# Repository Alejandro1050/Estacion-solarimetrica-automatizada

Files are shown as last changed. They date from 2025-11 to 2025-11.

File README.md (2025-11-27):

# 🌞 Sistema Automatizado de Adquisición de Datos Solarimétricos

Prototipo de un sistema automatizado para la adquisición, procesamiento y visualización de datos solarimétricos en Cancún, Quintana Roo.

**Proyecto Terminal** - Ingeniería en Datos e Inteligencia Organizacional | Ingeniería Ambiental con especialidad en Energías Renovables

---

## 📋 Tabla de Contenidos

- [Descripción del Proyecto](#descripción-del-proyecto)
- [Características](#características)
- [Estructura del Proyecto](#estructura-del-proyecto)
- [Instalación](#instalación)
- [Configuración](#configuración)
- [Uso](#uso)
- [Especificaciones Técnicas](#especificaciones-técnicas)
- [Autores](#autores)
- [Licencia](#licencia)

---

## 📖 Descripción del Proyecto

Este repositorio contiene toda la documentación, código y especificaciones de hardware necesarias para un sistema completo de monitoreo solar. El sistema realiza la adquisición automática de datos solarimétricos, procesamiento en tiempo real (ETL), y visualización mediante un dashboard interactivo en Dash.

### Objetivos

- ✅ Automatizar la adquisición de datos solarimétricos
- ✅ Procesar y almacenar datos de forma eficiente
- ✅ Visualizar datos en tiempo real mediante dashboard web
- ✅ Generar alertas automáticas por anomalías
- ✅ Mantener historial completo de mediciones

---

## ⭐ Características

- **Backend robusto**: Servidor Python con ETL automático, MQTT y API REST
- **Frontend interactivo**: Dashboard en tiempo real con Dash
- **Microcontroladores**: Firmware especializado para ESP32 y Arduino
- **Múltiples sensores**: Piranómetros, termopares y sensores ambientales
- **Logging centralizado**: Sistema de logs con rotación automática
- **Alertas por email**: Notificación de anomalías en tiempo real
- **Simulación**: Modo simulador para pruebas sin hardware

---

## 📁 Estructura del Proyecto

```
Estacion-solarimetrica-automatizada/
├── Backend/                          # Servidor Python
│   ├── main.py                      # Gestor principal de procesos
│   ├── endpoint.py                  # API REST
│   ├── etl.py                       # Procesamiento de datos
│   ├── load.py                      # Carga a base de datos
│   ├── email_alert.py               # Sistema de alertas por email
│   ├── graficas_insolacion.py       # Generación de gráficos
│   ├── logging_config.py            # Configuración de logs
│   └── simulador.py                 # Simulador de datos
├── Frontend/                         # Interfaz web
│   └── app.py                       # Dashboard Dash
├── Modulos/                          # Hardware y Firmware
│   ├── Ambiental/                   # Módulo de temperatura/humedad
│   │   ├── Firmware/
│   │   │   ├── Arduino_dht/
│   │   │   └── ESP32_sht/
│   │   └── PCB/
│   ├── Datalogger/                  # Módulo datalogger
│   │   ├── Firmware/
│   │   │   ├── Datalogger/
│   │   │   ├── Datalogger_V2/
│   │   │   ├── Datalogger_V3/
│   │   │   └── Datalogger_V4/
│   │   └── PCB/
│   └── Termopares/                  # Módulo termopares
│       ├── Firmware/
│       │   └── Arduino_termo/
|       |   |__ ESP32_termo/
│       └── PCB/
├── LICENSE
└── README.md
```

---

## 💻 Instalación

### Requisitos Previos

- **Python 3.13** o superior
- **Mosquitto Broker** para comunicación MQTT
- **pip** (gestor de paquetes de Python)

### Paso 1: Clonar el Repositorio

```bash
git clone https://github.com/Alejandro1050/Estacion-solarimetrica-automatizada.git
cd Estacion-solarimetrica-automatizada
```

### Paso 2: Instalar Mosquitto Broker

```bash
# En sistemas Debian/Ubuntu
sudo apt update
sudo apt install mosquitto mosquitto-clients

# Iniciar el servicio
sudo systemctl start mosquitto
sudo systemctl enable mosquitto
```

### Paso 3: Instalar Dependencias Python

```bash
# Crear entorno virtual (recomendado)
python3 -m venv venv
source venv/bin/activate

# Instalar paquetes
pip3 install -r requirements.txt
```

### Paso 4: Cargar Firmware en Microcontroladores

1. **Datalogger**: Usar Arduino IDE para cargar `Modulos/Datalogger/Firmware/Datalogger_V4/Datalogger_V4.ino`
2. **Módulo Ambiental**: Cargar `Modulos/Ambiental/Firmware/ESP32-Ambi/ESP32-Ambi.ino`
3. **Termopares**: Cargar `Modulos/Termopares/Firmware/Termocuplas/Termocuplas.ino`

---

## ⚙️ Configuración

### Ubicación Geográfica

Ubicación instalada en Cancún, Quintana Roo:

| Parámetro | Valor |
|---|---|
| **Latitud** | 21°54'07" N |
| **Longitud** | 86°49'48" O |
| **Altura** | 6 m sobre el nivel del mar |
| **Zona horaria** | America/Cancun (UTC-6, UTC-5 con DST) |

### Configuración de Piranómetros

El sistema cuenta con dos piranómetros de precisión estándar (SPP):

| Sensor | Modelo | Constante Calibración | Canal Datalogger | Medición |
|---|---|---|---|---|
| **Piranómetro 1** | SPP | 8.66 µV/(W/m²) | Canal 1 | DHI (Irradiancia Horizontal Difusa) |
| **Piranómetro 2** | SPP | 8.72 µV/(W/m²) | Canal 2 | GHI (Irradiancia Horizontal Global) |

### Variables Medidas

El sistema recopila las siguientes variables:

- **DHI**: Irradiancia Horizontal Difusa (W/m²)
- **GHI**: Irradiancia Horizontal Global (W/m²)
- **DNI**: Irradiancia Normal Directa (W/m²) - calculada
- **Temperatura 1**: Termocupla 1 (°C)
- **Temperatura 2**: Termocupla 2 (°C)
- **Temperatura Ambiente**: Sensor SHT31 (°C)
- **Humedad Ambiente**: Sensor SHT31 (%)
- **Ángulo Cenital Solar**: Calculado en tiempo real (°)

---

## 🚀 Uso

### Iniciar el Sistema Completo

```bash
# Con entorno virtual activado
cd Backend
python3 main.py
```

Esto inicia automáticamente:
- ETL (procesamiento de datos)
- Endpoint API (disponible en `http://localhost:5001`)
- Frontend (dashboard disponible en `http://localhost:8050`)

### Ejecutar Componentes de Forma Independiente

**Solo Backend (API + ETL)**:
```bash
cd Backend
python3 main.py
```

**Solo Frontend (Dashboard)**:
```bash
cd Frontend
python3 app.py
```

**Modo Simulador** (para pruebas sin hardware):
```bash
cd Backend
python3 simulador.py
```

### Acceder al Dashboard

Una vez iniciado el sistema, abre tu navegador en:

```
http://localhost:8050
```

El dashboard te permite:
- Ver gráficos en tiempo real
- Consultar historial de datos
- Monitorear alertas
- Descargar datos

---

## 🔧 Especificaciones Técnicas

### Stack Tecnológico

**Backend:**
- Python 3.13
- Flask/API REST
- MQTT (Mosquitto)
- Polars para procesamiento de datos

**Frontend:**
- Dash (Plotly)
- Bootstrap para UI
- WebSocket para tiempo real

**Hardware:**
- ESP32-C3 para adquisición
- Piranómetros SPP
- Termopares tipo K
- Sensor SHT31

### Comunicación

- **MQTT**: Comunicación en tiempo real con sensores (puerto 1883)
- **REST API**: Acceso a datos históricos (puerto 5001)
- **HTTP**: Dashboard web (puerto 8050)

## 📊 Funcionalidades Principales

### ETL (Extract, Transform, Load)
- Extrae datos de MQTT en tiempo real
- Transforma y valida mediciones
- Calcula variables derivadas (DNI, ángulo zenital)
- Carga en base de datos

### Alertas
- Detección de anomalías automática
- Notificaciones por email
- Histórico de alertas

### Visualización
- Gráficos interactivos en tiempo real
- Análisis histórico
- Exportación de datos

---

## 🐛 Troubleshooting

**El dashboard no se conecta:**
- Verificar que Mosquitto está corriendo: `systemctl status mosquitto`
- Verificar logs: `tail -f data/logs/solarserver.log`

**Error de conexión MQTT:**
- Reiniciar Mosquitto: `sudo systemctl restart mosquitto`
- Verificar firewall: `sudo ufw allow 1883`

**API no responde:**
- Verificar que endpoint.py está ejecutándose
- Revisar puerto 5001: `lsof -i :5001`

---

## 📝 Licencia

Este proyecto está licenciado bajo [ver LICENSE](./LICENSE)

---

## 👥 Autores

Mel josé Cahuich Garcia - ing. ambiental 

Correo: 200300847@ucaribe.edu.mx

Carlos Alejandro Cordova Cocom - Ing. en datos e inteligencia organizacional

correo: 200300617@ucaribe.edu.mx

Nayeli Pérez Tun - Ing. ambiental 

correo: 200300850@ucaribe.edu.mx

Paola Ariana Tut Cupul - Ing. ambiental 

correo: 200300832@ucaribe.edu.mx

---

## 📞 Soporte

Para reportar problemas o sugerencias, crea un [issue](https://github.com/Alejandro1050/Estacion-solarimetrica-automatizada/issues) en el repositorio.

---

**Última actualización**: 27 de noviembre de 2025

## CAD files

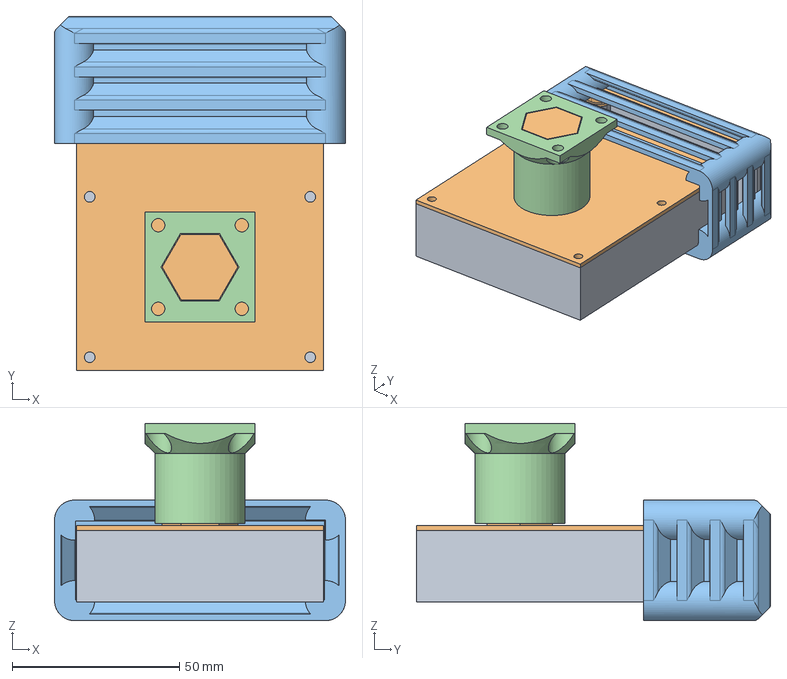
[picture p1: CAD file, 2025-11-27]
Modulos/Ambiental/Step files/Módulo ambiental V2.step
87.1 x 106.0 x 59.0 mm

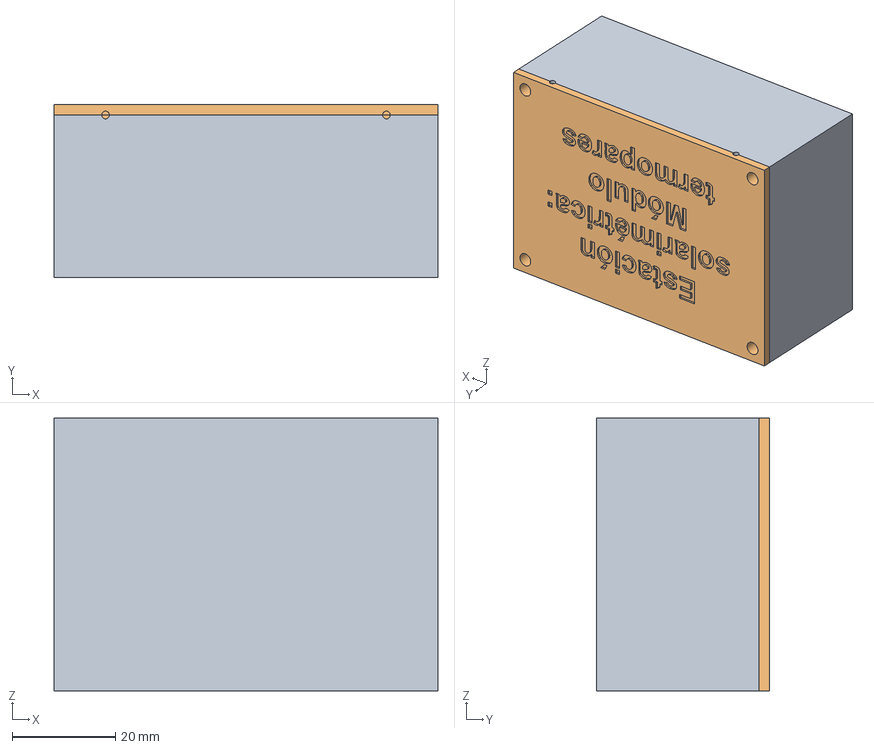
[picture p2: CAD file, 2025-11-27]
Modulos/Termopares/Step files/Módulo termocúplas.step
74.5 x 33.5 x 52.9 mm

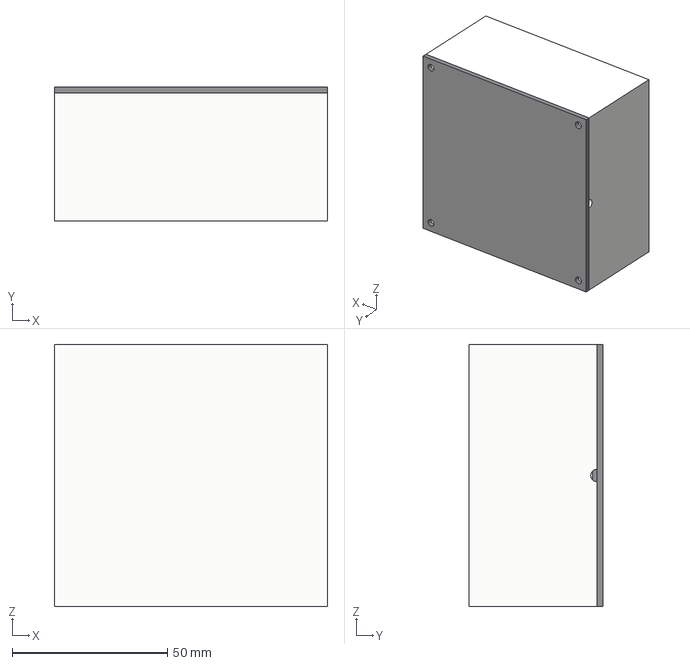
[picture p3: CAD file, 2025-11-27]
Modulos/Termopares/Step files/Termopares V1.step
87.8 x 43.2 x 84.4 mm

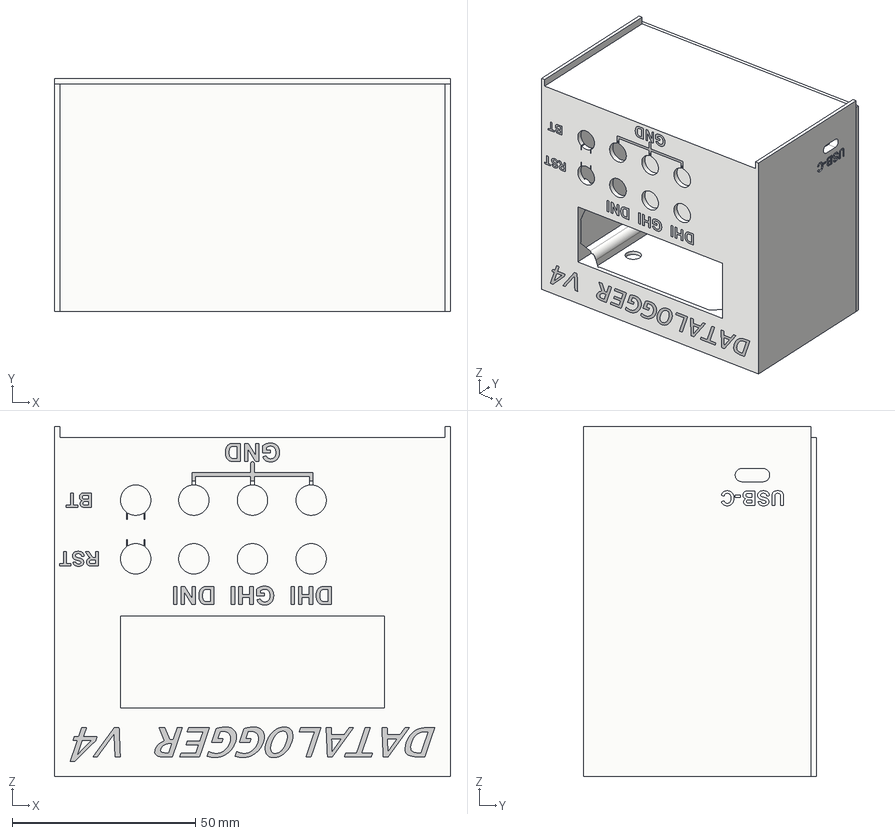
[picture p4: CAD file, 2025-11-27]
Modulos/Datalogger/Step files/Datalogger V3.step
108.0 x 63.6 x 95.6 mm

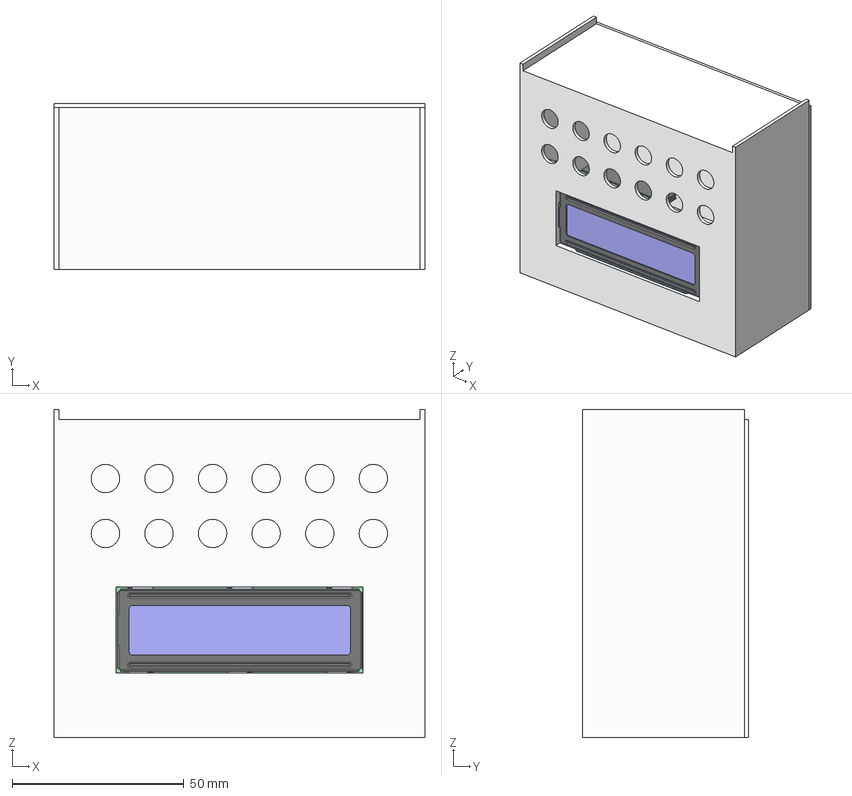
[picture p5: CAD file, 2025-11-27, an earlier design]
Modulos/Datalogger/Step files/Datalogger V2.step
108.0 x 48.3 x 95.6 mm
LCD_PCB
metal_casing
LCDbacklight
LCD_1
conductors x 2
1x8 Male Pin Header x 2
Header Female 1x16.step

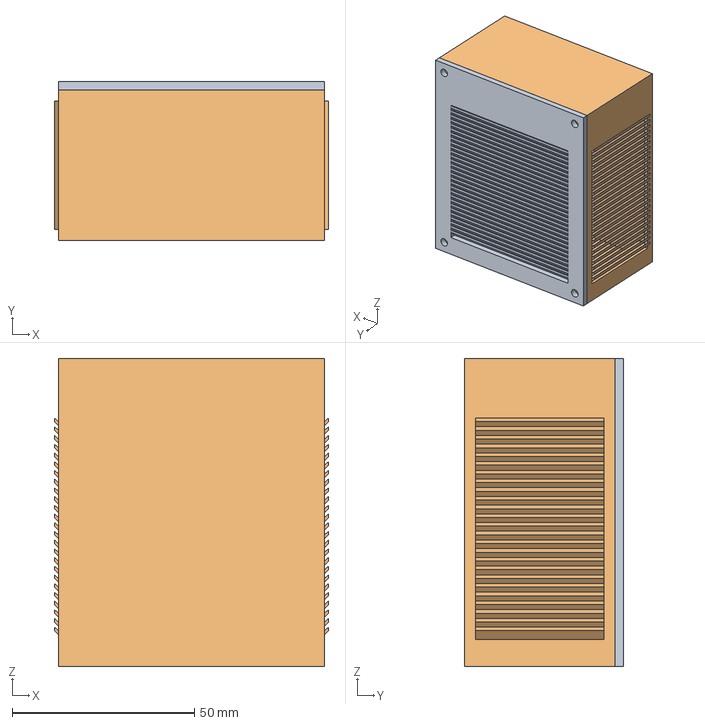
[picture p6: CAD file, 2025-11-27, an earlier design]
Modulos/Ambiental/Step files/Módulo ambiental v1.step
75.1 x 43.6 x 84.4 mm

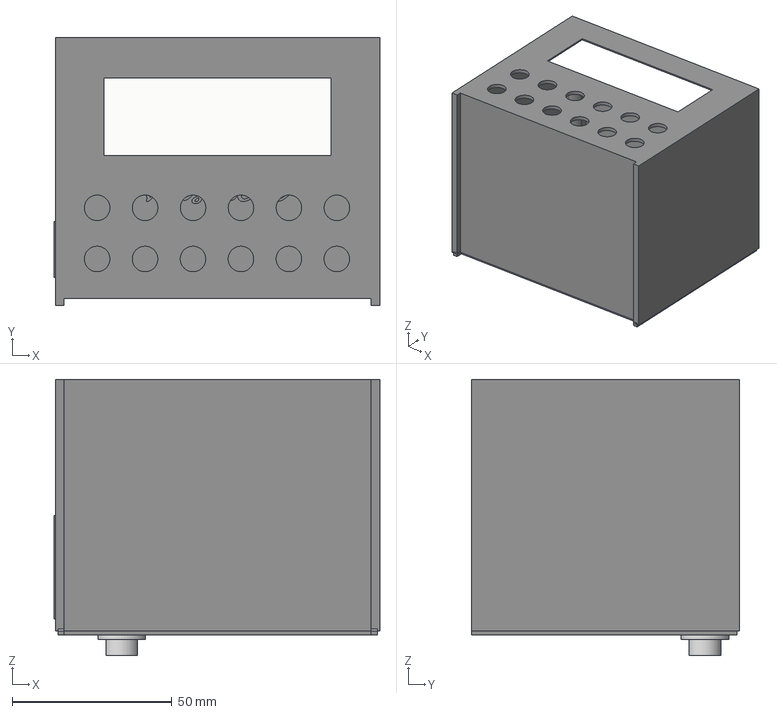
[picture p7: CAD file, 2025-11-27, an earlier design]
Modulos/Datalogger/Step files/Datalogger V1.step
102.0 x 83.8 x 86.5 mm

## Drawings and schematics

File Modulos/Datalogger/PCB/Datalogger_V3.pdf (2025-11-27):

Placa Principal | Placa I2C

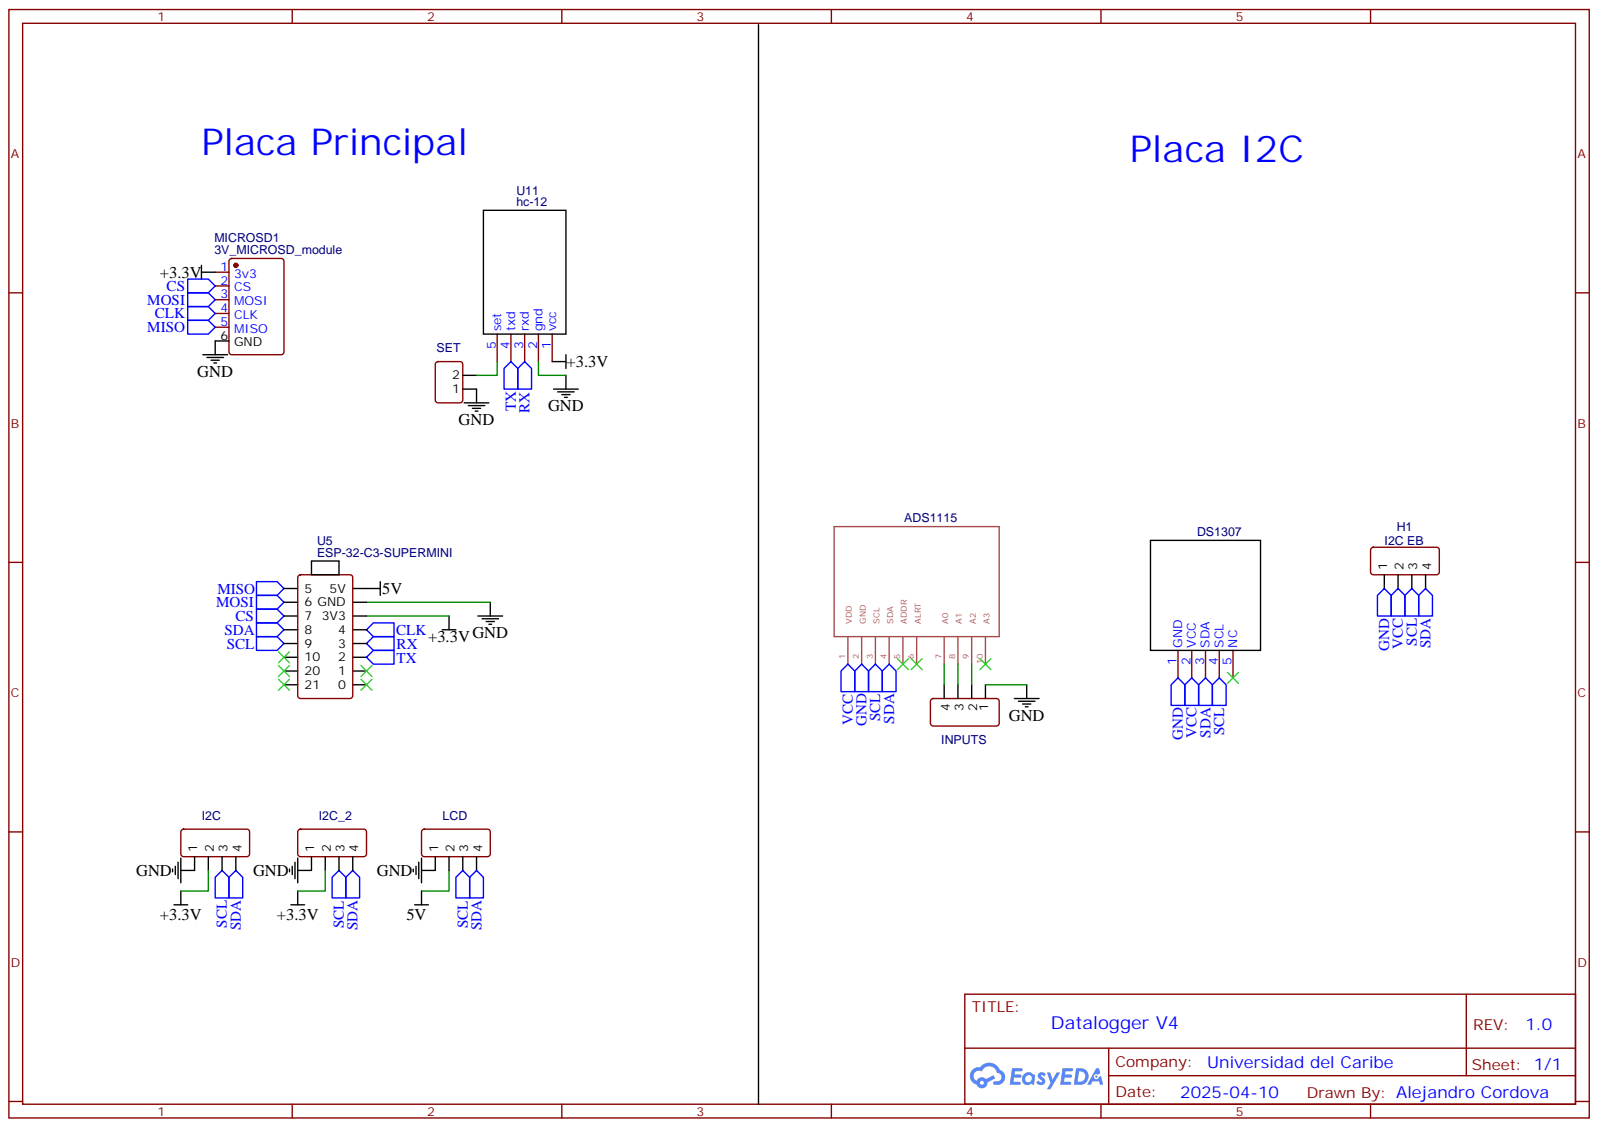
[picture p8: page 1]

Company: Universidad del Caribe

Drawn By: Alejandro Cordova

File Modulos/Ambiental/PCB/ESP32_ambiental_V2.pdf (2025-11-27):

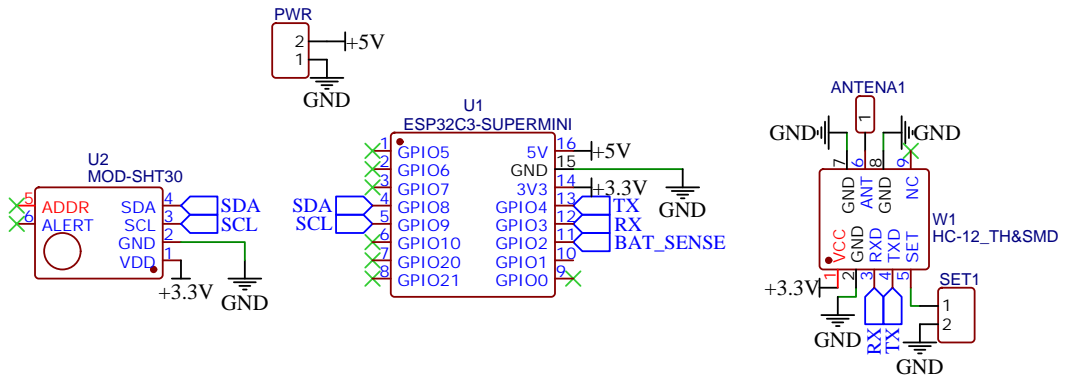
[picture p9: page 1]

Company: Universidad del Caribe

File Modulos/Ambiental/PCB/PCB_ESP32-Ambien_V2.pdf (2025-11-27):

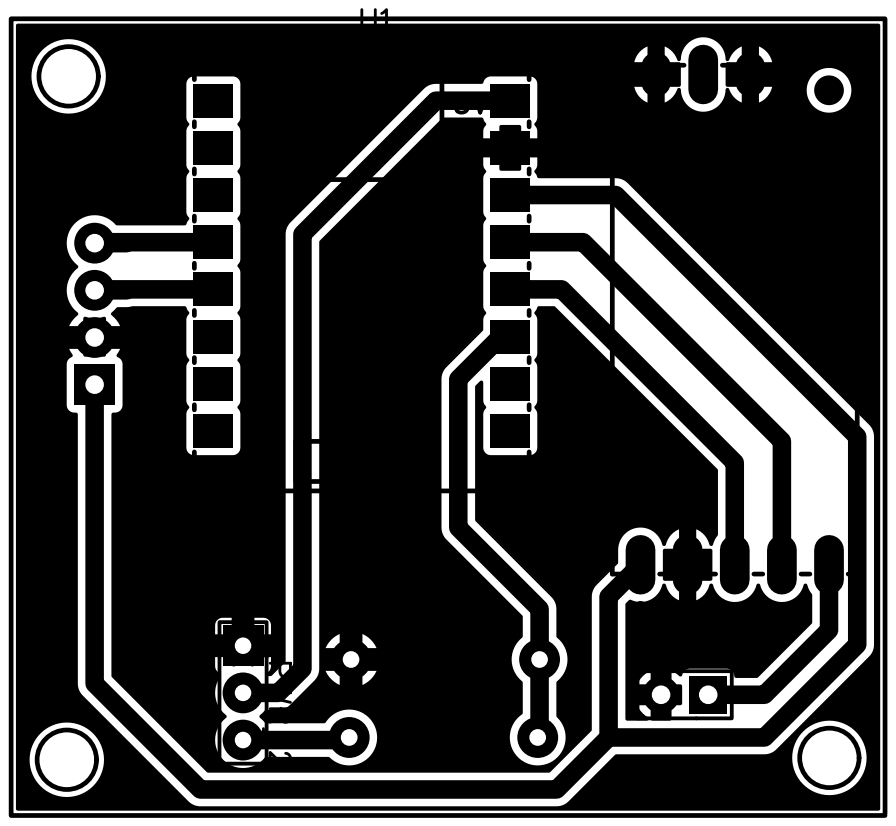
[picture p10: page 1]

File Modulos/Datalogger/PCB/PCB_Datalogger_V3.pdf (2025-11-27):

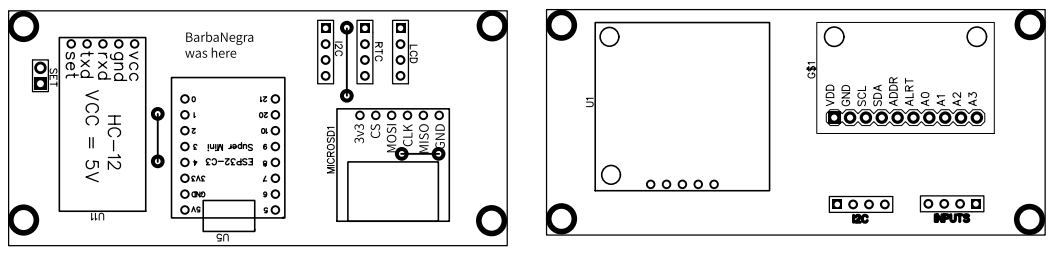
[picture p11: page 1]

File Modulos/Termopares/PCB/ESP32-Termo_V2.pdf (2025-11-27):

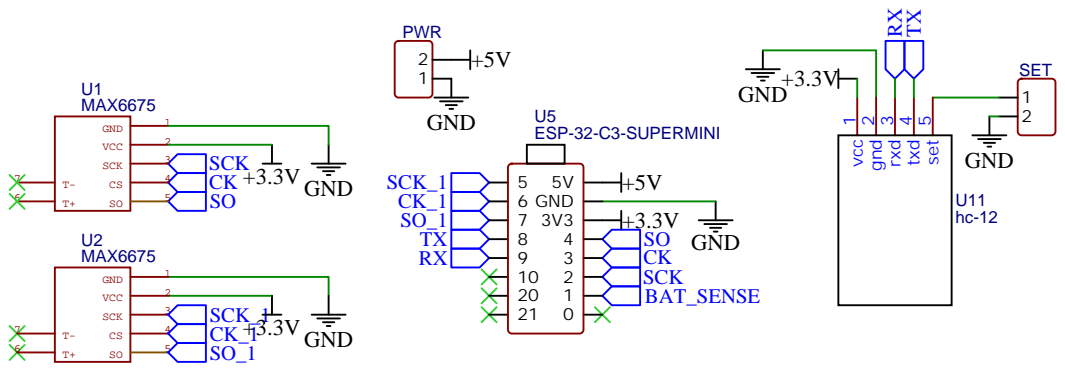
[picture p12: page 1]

Company: Universidad del Caribe

Drawn By: Alejandro Cordova

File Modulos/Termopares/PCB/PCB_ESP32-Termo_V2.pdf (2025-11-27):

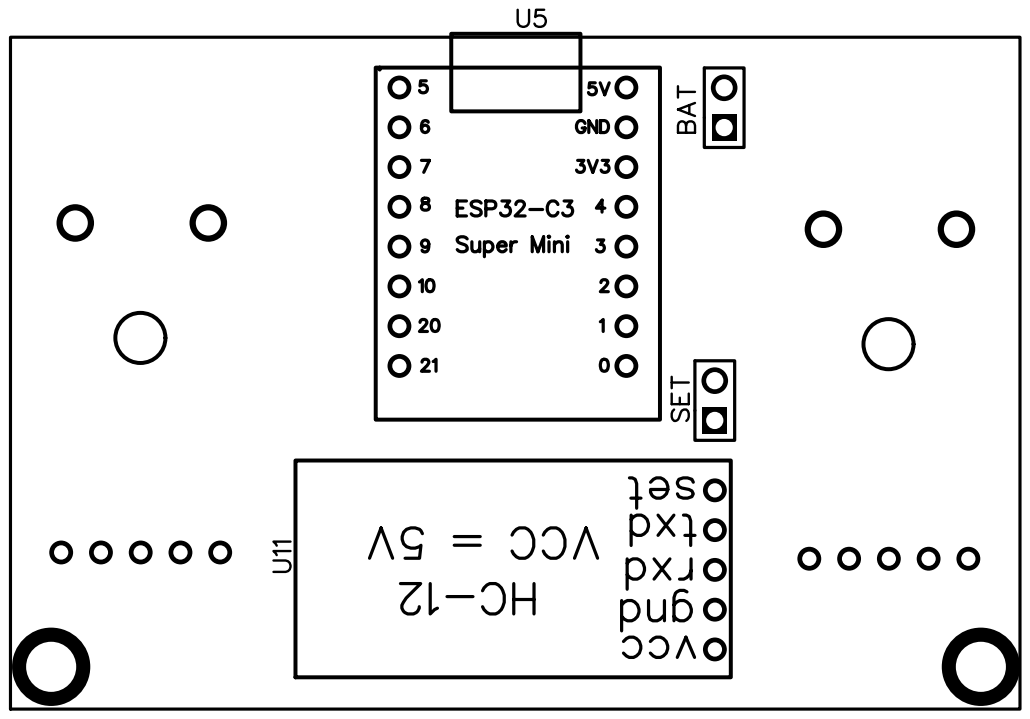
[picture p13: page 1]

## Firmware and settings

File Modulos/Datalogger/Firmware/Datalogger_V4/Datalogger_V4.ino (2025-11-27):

#include "FS.h"
#include "SD.h"
#include "SPI.h"
#include <Wire.h>
#include <Adafruit_ADS1X15.h>
#include <WiFi.h>
#include <PubSubClient.h>
#include "RTClib.h"
#include <LiquidCrystal_I2C.h>

RTC_DS1307 rtc;

LiquidCrystal_I2C lcd(0x27, 16, 2);

// Configuración WiFi
const char* ssid = "LER";
const char* password = "datos_manda";

// Configuración MQTT
const char* mqtt_server = "192.168.1.3";
const int mqtt_port = 1883;
const char* mqtt_topic = "esp32/sensors";
const char* mqtt_command_topic = "esp32/commands";

// Definición de pines
#define HC12_RX_PIN 3  // Conectar TX del HC-12
#define HC12_TX_PIN 2  // Conectar RX del HC-12
#define SD_CS_PIN 7    // Pin Chip Select para la SD

HardwareSerial hc(1);  // UART1 para HC-12
Adafruit_ADS1115 ads;

// Variables para el manejo del tiempo
const long interval = 60000;
unsigned long previousMillis = 0;

// Variables de estado
bool SD_Error = false;
bool wifiConnected = false;
bool mqttConnected = false;
int connectionAttempts = 0;
File dataFile;

// Inicializar el cliente WiFi y MQTT
WiFiClient espClient;
PubSubClient client(espClient);

// Función para conectarse al Wifi
void setup_wifi() {
  delay(10);
  Serial.println();
  Serial.print("Conectando a: ");
  Serial.println(ssid);

  lcd.clear();
  lcd.setCursor(0, 0);
  lcd.print("Conectando WiFi");
  lcd.setCursor(0, 1);
  lcd.print(ssid);

  // Configuración específica para ESP32-C3
  WiFi.mode(WIFI_STA);
  WiFi.setAutoReconnect(true);
  WiFi.setTxPower(WIFI_POWER_19_5dBm);  // Aumentar potencia de transmisión
  WiFi.setHostname("Datalogger-C3");

  // Limpiar configuración previa
  WiFi.disconnect(true);
  delay(2000);

  // Configurar parámetros WiFi específicos
  WiFi.setScanMethod(WIFI_ALL_CHANNEL_SCAN);
  WiFi.setSortMethod(WIFI_CONNECT_AP_BY_SIGNAL);

  Serial.println("Iniciando conexión...");
  WiFi.begin(ssid, password);

  int attempts = 0;
  while (WiFi.status() != WL_CONNECTED && attempts < 25) {
    delay(1000);
    Serial.print("Intento ");
    Serial.print(attempts);
    Serial.print(" - Estado: ");
    Serial.println(WiFi.status());

    // Mostrar punto en LCD
    lcd.setCursor(attempts, 1);
    lcd.print(".");

    attempts++;

    // Reiniciar conexión después de 10 intentos
    if (attempts == 10) {
      Serial.println("Reiniciando conexión WiFi...");
      WiFi.disconnect();
      delay(1000);
      WiFi.begin(ssid, password);
    }
  }

  if (WiFi.status() == WL_CONNECTED) {
    wifiConnected = true;
    Serial.println("WiFi CONECTADO!");
    Serial.print("IP: ");
    Serial.println(WiFi.localIP());
    Serial.print("RSSI: ");
    Serial.println(WiFi.RSSI());

    lcd.clear();
    lcd.setCursor(0, 0);
    lcd.print("WiFi Conectado");
    lcd.setCursor(0, 1);
    lcd.print("IP: ");
    lcd.print(WiFi.localIP());
  } else {
    wifiConnected = false;
    Serial.println("FALLA en conexión WiFi");
    Serial.print("Último estado: ");
    Serial.println(WiFi.status());

    lcd.clear();
    lcd.setCursor(0, 0);
    lcd.print("Error WiFi");
    lcd.setCursor(0, 1);
    lcd.print("Estado ");
    lcd.print(WiFi.status());
  }
  delay(2000);
}

void wifiDiagnostic() {
  Serial.println("\n=== DIAGNÓSTICO WiFi DETALLADO ===");

  // Verificar si el SSID está disponible
  Serial.println("Escaneando redes...");
  int n = WiFi.scanNetworks();
  Serial.print("Redes encontradas: ");
  Serial.println(n);

  bool networkFound = false;
  for (int i = 0; i < n; ++i) {
    Serial.print(i + 1);
    Serial.print(": ");
    Serial.print(WiFi.SSID(i));
    Serial.print(" (");
    Serial.print(WiFi.RSSI(i));
    Serial.print(" dBm) ");
    Serial.println((WiFi.encryptionType(i) == WIFI_AUTH_OPEN) ? "Abierta" : "Protegida");

    if (WiFi.SSID(i) == ssid) {
      networkFound = true;
      Serial.print("*** RED LER ENCONTRADA - Señal: ");
      Serial.print(WiFi.RSSI(i));
      Serial.println(" dBm ***");
    }
  }

  if (!networkFound) {
    Serial.println("*** ADVERTENCIA: Red LER no encontrada ***");
  }

  Serial.print("Estado WiFi: ");
  switch (WiFi.status()) {
    case WL_IDLE_STATUS: Serial.println("WL_IDLE_STATUS (0)"); break;
    case WL_NO_SSID_AVAIL: Serial.println("WL_NO_SSID_AVAIL (1) - SSID no disponible"); break;
    case WL_SCAN_COMPLETED: Serial.println("WL_SCAN_COMPLETED (2)"); break;
    case WL_CONNECTED: Serial.println("WL_CONNECTED (3)"); break;
    case WL_CONNECT_FAILED: Serial.println("WL_CONNECT_FAILED (4) - Falló conexión"); break;
    case WL_CONNECTION_LOST: Serial.println("WL_CONNECTION_LOST (5) - Conexión perdida"); break;
    case WL_DISCONNECTED: Serial.println("WL_DISCONNECTED (6) - Desconectado"); break;
    default: Serial.println("Desconocido"); break;
  }

  Serial.print("MAC: ");
  Serial.println(WiFi.macAddress());
  Serial.println("=== FIN DIAGNÓSTICO ===\n");
}
void reconnectMQTT() {
  while (!client.connected() && connectionAttempts < 10) {
    Serial.print("Intentando conexión MQTT...");
    lcd.clear();
    lcd.setCursor(0, 0);
    lcd.print("Servidor:");
    lcd.setCursor(0, 1);
    lcd.print("Conectando...");
    delay(500);

    // Crear un ID de cliente aleatorio
    String clientId = "DATALOGGER-";
    clientId += String(random(0xffff), HEX);

    // Intentar conectar
    if (client.connect(clientId.c_str())) {
      Serial.println("conectado");
      lcd.clear();
      lcd.setCursor(0, 0);
      lcd.print("Servidor:");
      lcd.setCursor(0, 1);
      lcd.print("Conectado");
      delay(500);

      // Suscribirse al tema de comandos
      client.subscribe(mqtt_command_topic);

    } else {
      Serial.print("falló, rc=");
      Serial.print(client.state());
      connectionAttempts++;
      if (connectionAttempts == 10) {
        mqttConnected = false;
        Serial.println("MQTT Error!");
        lcd.clear();
        lcd.setCursor(0, 0);
        lcd.print("Servidor:");
        lcd.setCursor(0, 1);
        lcd.print("Error!");
        delay(500);
      } else {
        Serial.println(" intentando de nuevo en 5 segundos");
      }
      delay(5000);
    }
  }
}

String getVoltage() {
  int16_t adc0 = ads.readADC_SingleEnded(0);
  int16_t adc1 = ads.readADC_SingleEnded(1);

  float ch1 = ads.computeVolts(adc0) * 1000.0f;
  float ch2 = ads.computeVolts(adc1) * 1000.0f;

  if (ch1 < 0.0 || ch1 > 11.0) {
    ch1 = 0.0;
  }
  if (ch2 < 0.0 || ch2 > 11.0) {
    ch2 = 0.0;
  }

  lcd.clear();
  lcd.setCursor(0, 0);
  lcd.print("Difusa (mv): ");
  lcd.setCursor(12, 0);
  lcd.print(ch1, 2);
  lcd.setCursor(0, 1);
  lcd.print("Global (mV): ");
  lcd.setCursor(12, 1);
  lcd.print(ch2, 2);

  return String(ch1, 2) + "," + String(ch2, 2);
}

String get_data(int id) {
  while (hc.available()) hc.read();  // Limpiar buffer
er
  hc.println(id);  // Enviar solicitud

  unsigned long startTime = millis();
  while (millis() - startTime < 1000) {
    if (hc.available()) {
      String data = hc.readStringUntil('\n');
      data.trim();
      if (data.length() > 0) {
        return data;
      }
    }
  }
  return "Nan,Nan,Nan";
}

bool init_SD() {
  if (!SD.begin(SD_CS_PIN)) {
    Serial.println("Error al inicializar la tarjeta SD");
    return false;
  }

  uint8_t cardType = SD.cardType();
  if (cardType == CARD_NONE) {
    Serial.println("No se detectó tarjeta SD");
    return false;
  }

  // Crear archivo con encabezados si no existe
  if (!SD.exists("/data.csv")) {
    File file = SD.open("/data.csv", FILE_WRITE);
    if (file) {
      file.println("Datetime,Pira_1(mV),Pira_2(mV),Termo1,Termo2,Bat_1,Temp_Amb,Hum_Amb,Bat_2");
      file.close();
    } else {
      Serial.println("Error al crear archivo");
      return false;
    }
  }

  return true;
}

void write_data(String message) {
  DateTime time = rtc.now();

  // Formatear fecha como DD-MM-YYYY HH:MM:SS
  char datetime[20];
  snprintf(datetime, sizeof(datetime), "%02d-%02d-%02d %02d:%02d:%02d",
           time.day(), time.month(), time.year(),       // DD-MM-YYYY
           time.hour(), time.minute(), time.second());  // HH:MM:SS

  String new_message = String(datetime) + "," + message;

  // Abrir archivo en modo append
  dataFile = SD.open("/data.csv", FILE_APPEND);

  if (dataFile) {
    if (dataFile.println(new_message)) {
      Serial.println("Datos guardados: " + new_message);
    } else {
      Serial.println("Error al escribir");
    }
    dataFile.close();
  } else {
    Serial.println("Error al abrir archivo");
    SD_Error = true;
  }
}

void mqttCallback(char* topic, byte* payload, unsigned int length) {
  Serial.print("Mensaje recibido [");
  Serial.print(topic);
  Serial.print("] ");

  // Convertir el payload a String
  String message = "";
  for (int i = 0; i < length; i++) {
    message += (char)payload[i];
  }
  Serial.println(message);

  // Verificar si es el tema de comandos y el mensaje es "get"
  if (String(topic) == mqtt_command_topic && message == "get") {
    LeerSensores();
    Serial.println("Comando GET recibido - Leyendo sensores");
  }
}

void LeerSensores() {

  String termopares = get_data(1);
  lcd.clear();
  lcd.setCursor(0, 0);
  lcd.print("Termopares:");
  lcd.setCursor(0, 1);
  lcd.print(termopares);

  delay(500);
  String ambiente = get_data(2);
  lcd.clear();
  lcd.setCursor(0, 0);
  lcd.print("Ambiental:");
  lcd.setCursor(0, 1);
  lcd.print(ambiente);

  String message = getVoltage() + "," + termopares + "," + ambiente;

  if (!SD_Error) {
    write_data(message);
  }

  Serial.println("Datos: " + message);

  // Publicar en el tema MQTT solo si estamos conectados
  if (client.connected()) {
    client.publish(mqtt_topic, message.c_str());
  }
}

void setup() {
  Serial.begin(115200);

  lcd.init();
  lcd.backlight();

  hc.begin(9600, SERIAL_8N1, HC12_RX_PIN, HC12_TX_PIN);

  lcd.clear();
  lcd.setCursor(0, 0);
  lcd.print("Iniciando sistema...");
  Serial.println("Iniciando sistema...");
  delay(1000);

  lcd.clear();

  // Ejecutar diagnóstico WiFi
  //wifiDiagnostic();

  ads.setGain(GAIN_SIXTEEN);
  //ads.setDataRate(RATE_ADS1115_64SPS);

  if (!ads.begin()) {
    Serial.println("ADC Error!");
    lcd.setCursor(0, 0);
    lcd.print("ADC Error!");
  } else {
    Serial.println("ADC OK!");
    lcd.setCursor(0, 0);
    lcd.print("ADC OK;");
  }

  delay(1000);
  lcd.clear()

    if (!rtc.begin()) {
    Serial.println("RTC Error!");
    lcd.setCursor(0, 0);
    lcd.print("RTC Error!");
    Serial.flush();
    while (1) delay(10);
  }
  lcd.setCursor(0, 1);
  lcd.print("RTC OK!");
  Datetime now = rtc.now();
  lcd.print(now.date());
  lcd.setCursor(0, 1);
  lcd.print(now.hour() + String(":") + now.minutes() + String(":") + now.seconds());
  delay(500);

  if (!rtc.isrunning()) {
    Serial.println("Ajustando RTC...");
    rtc.adjust(DateTime(F(__DATE__), F(__TIME__)));
  }

  setup_wifi();

  if (wifiConnected) {
    client.setServer(mqtt_server, mqtt_port);
    client.setCallback(mqttCallback);

    // Dar tiempo para que la conexión WiFi se estabilice
    delay(1000);

    reconnectMQTT();

    if (client.connected()) {
      Serial.println("MQTT conectado exitosamente");
      mqttConnected = true;
    } else {
      Serial.println("MQTT no conectado - continuando en modo offline");
      mqttConnected = false;
      ;
    }
  }

  // Inicializar SD con reintentos
  for (int i = 0; i < 3; i++) {
    if (init_SD()) {
      SD_Error = false;
      break;
    }
    delay(1000);
  }
  lcd.clear();
  if (SD_Error) {
    Serial.println("Sistema iniciado sin tarjeta SD");
    lcd.clear();
    lcd.setCursor(0, 0);
    lcd.print("Sistema iniciado");
    lcd.setCursor(0, 1);
    lcd.print("SD Error!");
  } else {
    Serial.println("Sistema iniciado correctamente");
    lcd.print("Sistema iniciado");
    lcd.setCursor(0, 1);
    lcd.print("Correctamente");
  }
}

void loop() {
  if (wifiConnected) {
    // Modo online - conexión con el servidor
    if (!client.connected()) {
      reconnectMQTT();
    }
    client.loop();
  }
  if (!wifiConnected || !mqttConnected) {
    // Modo offline - solo guardar en SD
    unsigned long currentMillis = millis();
    if (currentMillis - previousMillis >= interval) {
      previousMillis = currentMillis;
      LeerSensores();
    }
  }
}

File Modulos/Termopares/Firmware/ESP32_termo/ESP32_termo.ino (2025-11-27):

#include "max6675.h"

// Pines para termocuplas en ESP32-C3
const int thermoDO = 2;   // Pin 2
const int thermoCS = 3;   // Pin 3
const int thermoCLK = 4;  // Pin 4

const int thermoDO_1 = 5;   // Pin 5
const int thermoCS_1 = 6;   // Pin 6
const int thermoCLK_1 = 7;  // Pin 7

MAX6675 thermocouple(thermoCLK, thermoCS, thermoDO);
MAX6675 thermocouple_1(thermoCLK_1, thermoCS_1, thermoDO_1);

// Configuración UART para HC-12
HardwareSerial hc(1);
#define HC12_RX_PIN 9  // Conectar TX del HC-12 aquí
#define HC12_TX_PIN 8  // Conectar RX del HC-12 aquí

const int bat_pin = A1;
int sensorValue = 0;
const float R1 = 10000.0;
const float R2 = 22000.0;

float temp_0 = 0.0;
float temp_1 = 0.0;

String bat_level(int adc) {
  float voltage = ((adc * (3.3 / 4095.0)) * ((R1 + R2) / R2)) - 0.60;

  return String(voltage);
}

void setup() {
  Serial.begin(115200);
  Serial.println("Termocuplas iniciadas");

  // Inicializar UART para HC-12
  hc.begin(9600, SERIAL_8N1, HC12_RX_PIN, HC12_TX_PIN);

  // Dar tiempo a las termocuplas para estabilizarse
  delay(1000);
}

void loop() {

  if (hc.available() > 0) {
    char input = hc.read();

    if (input == '1') {
      // Leer temperaturas
      temp_0 = thermocouple.readCelsius();
      temp_1 = thermocouple_1.readCelsius();
      //temp_0 = 60.5;
      //temp_1 = 66.6;

      if (isnan(temp_0)) temp_0 = -999.99;
      if (isnan(temp_1)) temp_1 = -999.99;

      sensorValue = analogRead(bat_pin);

      String response = String(temp_0) + "," + String(temp_1) + "," + String(bat_level(sensorValue)) + "\n";
      hc.println(response);

      Serial.print("Temperaturas enviadas: ");
      Serial.println(response);
    }
  }
}
